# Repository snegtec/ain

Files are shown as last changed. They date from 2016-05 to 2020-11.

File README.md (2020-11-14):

/*****************************************************************************
*
* AIN Led Module
* a simple led module with a microcontroller for Petzl Duo Led headlamp
* 
* Note: This is just a hobby project. I am not connected in any way with 
* Petzl company.
* 
* version: 0.1 (November 2020)
* author: Erik Kos
*          snegtec.com
*          snegtec@outlook.com
* 
* Copyright (C) 2014-2016 Erik Kos
* 
* License:
*   application, source code - GNU General Public License
*   hardware (schematics, pcb design) - Creative Commons Attribution 
*   Share-Alike license (CC BY-SA 4.0)
* 
****************************************************************************/

Used tools
* compiler: Atmel Studio 6
* application for pcb design: Eagle 6.5.0.

Notes/problems/bugs/limitations:
* This is very simple module. Don't expect exciting features.
* One 7135 driver is enough for one side FR4 pcb.
* There has to be a schottky diode. Standard diode disables change of modes when battery is out. If you want to use BAT54C SOT23 package (or similar) you have to change the pcb.
* It is enough to give 10uF ceramic capacitor. Memory is back up well - ATTiny takes below 1uA in power down state.
* ATtiny13 has too small flash memory to be good for such project. If you want to add some features - use ATMega328 or similar.
* The pcb size is an approximation. Check the size and alignment of power pins before ordering a pcb.
* Soldering pins for ISP may be tricky.

time to discharge (to 0,9v per accu, approximatelly): 
* main mode: 3h 
* 1/2 mode: 6h
* 1/4 mode: 12h
* dim mode: ?h

/****************************************************************************/

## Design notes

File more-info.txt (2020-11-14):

/****************************************************************************/

Ain - a led module

A simple power led module for Petzl Duo caving headlamp
Introduction

Petzl Duo is a bit old but still very good headlamp produced by Petzl company. But in 2014 year it was equipped with an outdated bulb and a very simple light module with 5 led diodes. There are very good market solutions which can replace old modules with a modern source of light. But I wanted to create such solution myself, just as a hobby project.

Why to choose Petzl Duo? There are so many good headlamps on the market. But Petzl Duo has very nice feature - it is very flexible because it allows modules with light source to be changed. So there is possible to put there any module one may dream of. Modern light modules are usually computer systems. So there is freedom in programming them up to programmer's taste and fun.

This is a removable module. It can be easily removed for a check or for a replacement. No need to use a screwdriver or other tool.
Power leds

It contains 2 power leds. There are used Cree XP-G power leds. First power led is equipped with Ledil Tina-RS (real spot) 15 degrees lens for a focused beam of light. Second power led uses Ledil Tina-D 20 degrees lens for an ambient light. Every led has 3 levels of light intensity.

Cree XP-G is a high power led. There are many color versions. Most of sensitivity of eyes lies in yellow light. But typical XP-G power led is weak in this part of light spectrum. So neutral white version of these diodes was used (3700-5000 K).

There is third lens. It is Tina-M (30 degrees). It is used for very weak night red light. The light is emitted by 2 pieces of red light 0805 led diodes. The purpose of this third light was to create ability to see in complete darkness and being not seen by others. The rods in the eye are not very sensitive to red light above 640 nm. Most red leds has output of 625-640 nm. So weak light should not be visible from greater distance. To prevent seeing the lens (which is always seen very well) it is enough just to lower the housing of headlamp.

The power leds are powered by one AMC7135 driver each. It provides about 340mA of current to each power diode. Drivers are controlled by an ATtiny13a microcontroller. It is a 8-bit AVR processor with just 1k of a flash memory for a program and 64 bytes of RAM. The 2 power leds has 3 levels of brightness. Pulse width modulation techique (PWM) is used for changing brightness of leds.
The module inside Petzl Duo headlamp on Rock Helmets Combi helmet
Special feature

A special feature is used to change light modes. The headlamp allows only turning on and off light. So to remember current mode there was need to add backup power source to save contents of memory of the microcontroller. It was put in power-down mode. So it was enough to use 10uF capacitor to protect its memory.

The single sided pcb was developed in Eagle software. It has approximate size 46x33 mm. 
Noted problems

1. Because of heat dissipation problems, it was used just one AMC7135 driver. The headlamp is closed tightly because it is waterproof up to 5 meters of depth. So it is difficult to add a radiator to outside of headlamp housing.

2. The pcb contained an isp 6 pin connector for easy programming with an additional programmer. Unfortunately, it was soldered in non-standard way and after some programming attempts the connector was broken.

There can be done many improvements but there are the really needed ones 

    Better quality pcb! :)
    It is better to use double sided pcb and thermal design from Cree XP-G datasheet.
    Add S.O.S. and quick/slow blinking additional modes

The module inside of headlamp housing

Note: This is just a hobby project. I am not connected in any way with Petzl company.

2014-2020 Erik Kos

/****************************************************************************/

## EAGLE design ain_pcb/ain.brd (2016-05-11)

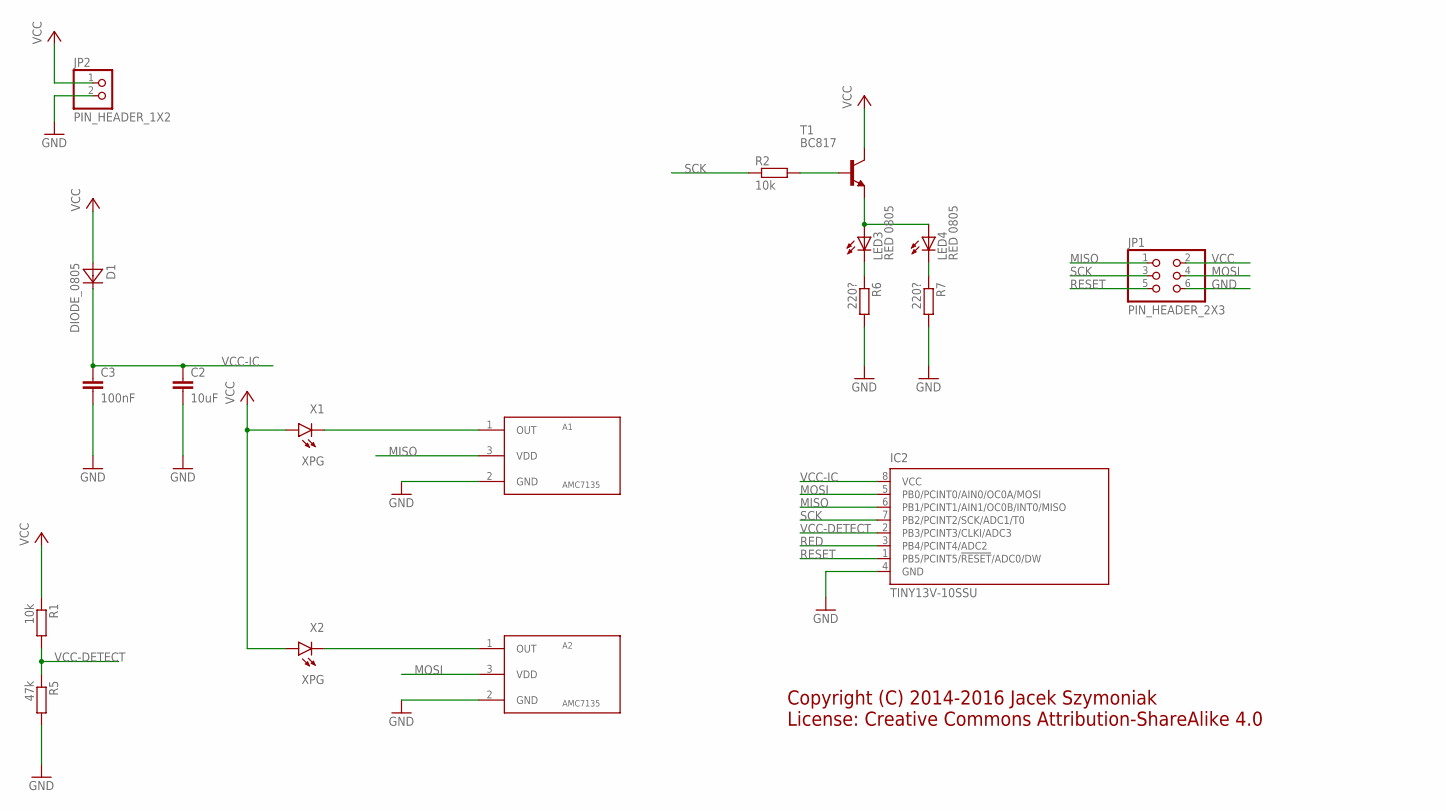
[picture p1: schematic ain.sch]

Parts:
A1, A2: AMC7135; SOT-89
C2: 10uF; C0805
C3: 100nF; C0805
D1: DIODE_0805; 0805
IC2: TINY13V-10SSU; 8S1
JP1: PIN_HEADER_2X3
JP2: PIN_HEADER_1X2
LED3, LED4: RED 0805; SML0805
R1, R2: 10k; M0805
R5: 47k; M0805
R6, R7: 220?; M0805
T1: BC817; SOT23-BEC
X1, X2: XPG

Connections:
GND: A1.2 (GND), A2.2 (GND), C2.2, C3.2, IC2.4 (GND), JP1.6, JP2.2, R5.2, R6.2, R7.2
MISO: A1.3 (VDD), IC2.6 (PB1/PCINT1/AIN1/OC0B/INT0/MISO), JP1.1
MOSI: A2.3 (VDD), IC2.5 (PB0/PCINT0/AIN0/OC0A/MOSI), JP1.4
unnamed: A2.1 (OUT), X2.2 (C)
unnamed: A1.1 (OUT), X1.2 (C)
unnamed: R2.2, T1.B
unnamed: LED3.A, LED4.A, T1.E
unnamed: LED4.C, R7.1
unnamed: LED3.C, R6.1
RED: IC2.3 (PB4/PCINT4/ADC2)
RESET: IC2.1 (PB5/PCINT5/!RESET!/ADC0/DW), JP1.5
SCK: IC2.7 (PB2/PCINT2/SCK/ADC1/T0), JP1.3, R2.1
VCC: D1.1 (A), JP1.2, JP2.1, R1.1, T1.C, X1.1 (A), X2.1 (A)
VCC-DETECT: IC2.2 (PB3/PCINT3/CLKI/ADC3), R1.2, R5.1
VCC-IC: C2.1, C3.1, D1.2 (C), IC2.8 (VCC)

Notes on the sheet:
Copyright (C) 2014-2016 Jacek Szymoniak License: Creative Commons Attribution-ShareAlike 4.0

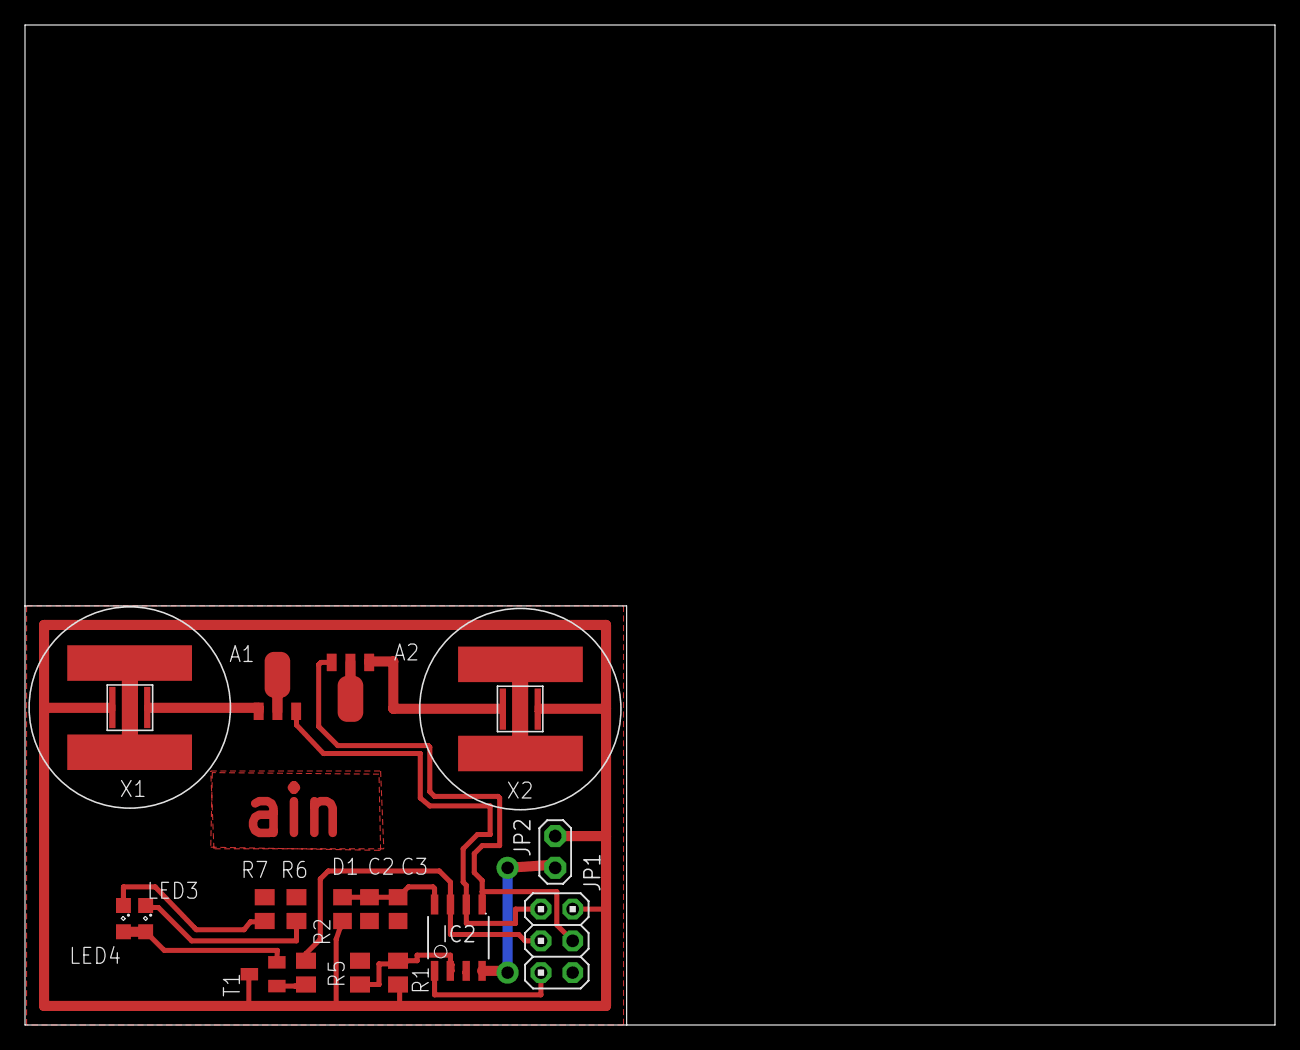
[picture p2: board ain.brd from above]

Board: 2 copper layers, 100.0 x 80.0 mm, 18 parts (0 on the bottom side), 14 nets.

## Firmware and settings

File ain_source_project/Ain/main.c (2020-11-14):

/*****************************************************************************
*
* AIN Led Module
* a simple led module with a microcontroller for Petzl Duo Led headlamp
* 
* Note: This is just a hobby project. I am not connected in any way with Petzl company.
* 
* version: 0.1 (March 2014)
* compiler: Atmel Studio 6
* author: Erik Kos
*          snegtec.com
*          snegtec@outlook.com
* 
* Copyright (C) 2014-2020 Erik Kos
* 
****************************************************************************
* 
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
****************************************************************************/

#include <avr/io.h>
#include <avr/interrupt.h>

// cpu frequency is defined in menu: Project/...properties/Toolchain/AVR/GNU C compiler/Symbols/F_CPU=128000UL
// cpu freqency is set by fuse bits not by definition by F_CPU; F_CPU is needed by delay.h

long timeCounter = 0;
short clicks = 0;
const short MAXTIME = 750;
long lastClickTime = 0;
long pcint3Time = 0;

short initialized = 0;
#define LEDA 1
#define LEDB 2
#define LEDRED 3

// attiny 13a
#define PIN_0 PB0
#define PIN_1 PB1
#define PIN_R PB2
#define PIN_VCC PB3

// change it in loadLastMode function
short mode = LEDA;

short brightness_a = 0;
short brightness_b = 0;
short brightness_r = 0;

short brightnesses[] = {255, 128, 64, 10};

void disablePin0()
{
	// disconnect pin OC0A
	// def TCCR0A &=~(1<<COM0A0);
	TCCR0A &=~(1<<COM0A1);
	
	// set low state
	PORTB &=~(1 << PIN_0);
}

void enablePin0()
{
	// connect pin OC0A
	// def TCCR0A &=~(1<<COM0A0);
	TCCR0A |=(1<<COM0A1);
}


void disablePin1()
{
	// disconnect pin OC0B
	// def TCCR0A &=~(1<<COM0B0);
	TCCR0A &=~(1<<COM0B1);

	// set low state
	PORTB &=~(1 << PIN_1);
}

void enablePin1()
{
	// connect pin OC0B
	// def TCCR0A &=~(1<<COM0B0);
	TCCR0A |= (1<<COM0B1);
}

void enableRed()
{
	// set pins as output
	DDRB = DDRB | (1 << PIN_R);
	
	// high state
	PORTB = PORTB | (1 << PIN_R);
}

void disableRed()
{
	// set pins as output
	// def DDRB = DDRB | (1 << PIN_R);
	
	// set low state
	PORTB &=~(1 << PIN_R);
}

void enablePwm()
{
	//************
	// pwm
	
	// pin configuration for pwm
	
	// DDR - set driver for OC0A and OC0B pins
	// set pins as output
	DDRB |= (1 << PIN_0);
	DDRB |= (1 << PIN_1);
	
	// waveform generation mode
	
	// mode 3, Fast PWM
	// def TCCR0B = TCCR0B & ~(1 << WGM02);
	TCCR0A = TCCR0A | (1 << WGM01);
	TCCR0A = TCCR0A |(1 << WGM00);
	
	
	// clock select
	// TCCR0B: CS02 CS01 CS00
	
	// clkio/1
	// def TCCR0B &=~ (1<<CS02);
	// def TCCR0B &=~ (1<<CS01);
	TCCR0B |= (1<<CS00);
}

void initialize_app()
{
	enablePwm();
	
	// enable interrupts for timer0
	TIMSK0 |= (1 << TOIE0);
	TIFR0 |= (1 << TOV0);
	
	
	//************
	// for checking presence of vcc
	
	// set pin as input
	DDRB = DDRB & ~(1 << PIN_VCC);
	
	// disable pullup
	PORTB &=~ (1<<PIN_VCC);

	// enable PCINT0 pin for interrupt
	PCMSK = PCMSK | (1<<PCINT3);
	
	// enable PCINT7..0 pins
	GIMSK = GIMSK | (1<<PCIE);
	
	//************
	// start interrupt system
	sei();
}


void disableTimer()
{
	// clkio/1
	// def TCCR0B &=~ (1<<CS02);
	// def TCCR0B &=~ (1<<CS01);
	TCCR0B &=~ (1<<CS00);
	
}

void enableTimer()
{
	// clkio/1
	// def TCCR0B &=~ (1<<CS02);
	// def TCCR0B &=~ (1<<CS01);
	TCCR0B |= (1<<CS00);
	
}

void loadBrightness()
{
	OCR0A = brightnesses[brightness_a];
	OCR0B = brightnesses[brightness_b];
}


void changeBrightness()
{
	if (mode == LEDA)
	{
		brightness_a++;
		if (brightness_a > 3)
		brightness_a = 0;
	}
	else if (mode == LEDB)
	{
		brightness_b++;
		if (brightness_b > 3)
		brightness_b = 0;
	}
	else if (mode == LEDRED)
	{
		brightness_r++;
		if (brightness_r > 3)
		brightness_r = 0;
	}
	loadBrightness();
}

void enableLed()
{
	if (mode == LEDA)
	{
		enablePin0();
		disablePin1();
		disableRed();
	}
	else if (mode == LEDB)
	{
		disablePin0();
		enablePin1();
		disableRed();
	}
	else if (mode == LEDRED)
	{
		disablePin0();
		disablePin1();
		enableRed();
	}
}


void changeMode()
{
	if (mode == LEDA)
	mode = LEDB;
	else if (mode == LEDB)
	{
		mode = LEDRED;
	}
	else if (mode == LEDRED)
	mode = LEDA;
	
	enableLed();
}

void disableLed()
{
	disablePin0();
	disablePin1();
	disableRed();
}

int main()
{
	initialize_app();
	
	brightness_a = 0;
	brightness_b = 0;
	brightness_r = 0;
	loadBrightness();
	
	mode = LEDA;
	enableLed();
	
	// main loop
	while (1)
	{}
	
}


ISR(TIM0_OVF_vect)
{
	
	// increment counters
	timeCounter++;
	
	// service of clicks
	if ((clicks == 1) && (timeCounter >= lastClickTime + (2 * MAXTIME)))
	{
		// wait one MAXTIME period to handle/service 1-clicks
		
		changeMode();
		
		lastClickTime = 0;
		
		timeCounter = 0;
		clicks = 0;
		} else if (clicks == 2) {
		// 2-click has to be taken immediately
		
		changeBrightness();
		
		lastClickTime = 0;
		
		timeCounter = 0;
		clicks = 0;
	}
	
	//************
	
	if (pcint3Time > 0 && timeCounter >= pcint3Time + 100)
	{
		pcint3Time = 0;
		
		// if vcc detection on PIN_VCC
		if (PINB & (1 << PIN_VCC))
		{
			lastClickTime = timeCounter;
			clicks++;
			
			enableLed();
		}
		else if ((PINB & (1 << PIN_VCC)) == 0)
		{
			// vcc is missing
			
			disableLed();
			
			disableTimer();
			
			// disable interrupts for timer0
			TIMSK0 &=~ (1 << TOIE0);
			TIFR0 &=~ (1 << TOV0);
			
			// start interrupt system
			sei();
			
			// enable idle state
			MCUCR |= (1 << SE);
			
			// power down
			MCUCR |= (1 << SM1);
			MCUCR &=~ (1 << SM0);
			
			// enter idle state
			asm ("sleep");
		}
	}
}


ISR(PCINT0_vect)
{
	pcint3Time = timeCounter;

	// if this interrupt disabled idle state
	if (MCUCR & (1 << SE))
	{
		// disable idle state
		MCUCR &=~ (1 << SE);
		
		enableTimer();
		
		// enable interrupts for timer0
		TIMSK0 |= (1 << TOIE0);
		TIFR0 |= (1 << TOV0);
		
	}
}

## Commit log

2016-05-11 full content
    full content - first public version
    [ain.brd, ain.sch]
2020-11-14 Added some description and changed some information
    [ain.sch]

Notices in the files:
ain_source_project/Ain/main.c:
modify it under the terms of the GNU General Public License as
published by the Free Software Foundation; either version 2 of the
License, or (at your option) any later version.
